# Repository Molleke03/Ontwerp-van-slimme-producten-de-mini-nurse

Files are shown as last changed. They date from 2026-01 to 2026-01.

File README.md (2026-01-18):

# CONVO 
*Convo, a tool for connection and conversation* <br>
_____
Convo is een innovatief communicatieapparaat ontworpen voor ouderen die zich eenzaam voelen of moeite hebben met moderne technologie. Veel bestaande digitale oplossingen zijn te complex, waardoor net de mensen die het meest nood hebben aan sociaal contact worden uitgesloten.

Het product richt zich op ouderen die eenvoud en duidelijkheid nodig hebben. Het apparaat bestaat uit een helder display, vier grote fysieke knoppen en ingebouwde speakers. Met één druk op de knop kunnen gebruikers eenvoudig contact maken met een familielid of een andere persoon die openstaat voor een babbeltje.

## Vormontwerp
Het ontwerp van CONVO is gebaseerd op de tijdloze designprincipes van BRAUN. De volledig witte behuizing wordt verfijnd door zachte zilveren accenten, die de draaiknop, drukknoppen en de afgeronde randen van de body subtiel benadrukken. Deze rustige en herkenbare vormgeving zorgt ervoor dat CONVO vertrouwd aanvoelt en harmonieus past binnen verschillende woonomgevingen.

github 2

### Ontwikkelproces van CONVO
Bij de creatie van het product werd gebruik gemaakt van de prusa MK4 3D-printer. Deze 3D-printe de knoppen, body, onderstel en de zijkanten. Volgende onderdelen werden allen uitgewerkt in de 3D-model software NX.

Schermafbeelding 2026-01-16 111215
<br>Welke setting, kleuren en hoe de onderdelen af te werken leggen we kort uit.

#### De knoppen
knoppen github

Alle knoppen werden geprint met:
- 0.15 mm QUALITY setting
- tree support
- 0.4 mm nozzle
- vulling van 15%

Knop 1 werd vervaardigd via 3D-printing met Polymaker Panchroma PLA Satin in de kleur groen.<br>
Knop 2 werd vervaardigd via 3D-printing met Polymaker Panchroma PLA Satin in de kleur rood. <br>
Knop 3, 4 en 5 werden vervaardigd via 3D-printing met Polymaker Panchroma PLA Satin in de kleur wit. Na het printproces werden de knoppen afgewerkt met een zilverkleurige spuitlak.

#### De body
body

Beide stukken werden geprint met:
- 0.15 mm QUALITY setting
- tree support
- 0.4 mm nozzle
- vulling van 30%
- Polymaker Panchroma PLA Satin in de kleur wit

Na het printproces werden van beide onderdelen de edges afgewerkt met een zilverkleurige spuitlak. Hierna werd het logo "CONVO" geplaatst op de behuizing met behulp van een stikker en werd ook dit afgewerkt met een zilveren spuitlak.

#### Het onderstel
onderstel

Volgend onderdeel werd geprint met:
- 0.15 mm QUALITY setting
- raster support
- 0.4 mm nozzle
- vulling van 15%
- Polymaker Panchroma PLA Satin in de kleur wit

#### De zijkanten
zijkanten

Volgend onderdeel werd geprint met:
- 0.15 mm QUALITY setting
- 0.4 mm nozzle
- vulling van 15%
- Polymaker Panchroma PLA Satin in de kleur wit

## Elektronica
### Benodigdheden
Het systeem bestaat uit:
- Raspberry Pi model 4B
- 5 inch HDMI-display (800x480 pixels)
- Audio amplifier TPA2016D2
- 2x speaker (3W, 8Ω)
- Encoder module (rotary encoder/ potentiometer))
- 4x drukknop
- USB-C → USB-A kabel met adapter
- Mini-HDMI → HDMI kabel
- Micro-USB → USB-A kabel met adapter
- 3.5 mm jack stereo → 2x RCA aux kabel (bewerkt)
- Arduino jumpdraadjes

### Aansluitingen
#### Raspberry Pi en voeding
De Raspberry Pi fungeert als het kloppend hart van het ontwerp en vormt de centrale besturingseenheid waaraan alle componenten zijn gekoppeld. De Raspberry Pi wordt gevoed via een USB-C-voeding die rechtstreeks op het elektriciteitsnet is aangesloten.

#### Display
De Raspberry Pi is via een HDMI-kabel verbonden met het 5 inch HDMI-display. Het videosignaal wordt digitaal via HDMI doorgestuurd.
Het display heeft een aparte voeding, die wordt aangesloten via een micro-USB-connector en een netadapter. Hierdoor kan het display onafhankelijk van de Raspberry Pi pinnen toch functioneren en wordt het beeld correct weergegeven.

#### Audio
Voor de geluidsuitvoer wordt gebruikgemaakt van de 3.5 mm stereo jack-uitgang van de Raspberry Pi. Deze uitgang is verbonden met een 3.5 mm jack naar 2 × RCA aux kabel.
De RCA-connectoren zijn afgeknipt zodat de afzonderlijke signaaldraden handmatig konden worden gesoldeerd.

De gesoldeerde Arduino-draadjes zijn aangesloten op de audio amplifier TPA2016D2 via de volgende aansluitingen:
- R+ en R- voor het rechter audiokanaal
- L+ en L- voor het linker audiokanaal

Om de audio amplifier correct te laten functioneren, zijn bijkomende verbindingen met de Raspberry Pi gemaakt:
- VDD en I2C van de amplifier zijn verbonden met de 5 V voeding van de Raspberry Pi (pin 2)
- GND van de amplifier is verbonden met GND van de Raspberry Pi (pin 14)

Aan de uitgangszijde van de audio amplifier zijn twee luidsprekers aangesloten. Hierbij wordt telkens de positieve pool (R+ en L+) met de positieve uitgang verbonden en de negatieve pool (R- en L-) met de negatieve uitgang.

#### Encoder module (potentiometer)
Voor het regelen van het volume wordt een encoder module gebruikt. Deze is als volgt aangesloten op de Raspberry Pi:
- GND → GND van de Raspberry Pi (pin 4)
- VCC (+) → 3.3 V van de Raspberry Pi (pin 17)
(de encoder werkt uitsluitend op 3.3 V)
- SW → GPIO25 (pin 22)
- DT → GPIO8 (pin 24)
- CLK → GPIO7 (pin 26)

Door het draaien van de encoder kan het volume aangepast worden.

#### Drukknoppen
Tot slot zijn er vier drukknoppen voorzien voor de bediening van het display en de gebruikersinterface. De knoppen zijn van links naar rechts toegewezen aan de volgende functies:
- Back
- Confirm
- Up
- Down

Elke drukknop is aangesloten volgens hetzelfde principe:
- Eén pin → GND van de Raspberry Pi (pin 6)
- Eén pin → GPIO-pin

De GPIO-toewijzing is als volgt:
- Back knop → GPIO23 (pin 16)
- Confirm knop → GPIO22 (pin 15)
- Up knop → GPIO27 (pin 13)
- Down knop → GPIO17 (pin 11)

Omdat meerdere draden op dezelfde pin van de Raspberry Pi uitkomen, worden hersluitbare lasklemmen van het merk Kopp gebruikt om de verbindingen overzichtelijk en veilig te houden.

Onderstaande afbeelding heeft het gehele schema weer om alles wat te verduidelijken.
Elektronica schema

## Code

### Uitvoeren
1. Start de Raspberry Pi en log in.
2. Plaats alle codebestanden, afbeeldingen en het geluidsfragment volgens de mapstructuur hieronder op de Raspberry Pi.
3. Pas de locatie van het geluidsfragment in `scene5.py` aan aan de hand van de locatie op de Raspberry Pi.
4. Open **Thonny Python IDE**.
5. Installeer vereiste **libraries** (zie onderstaande sectie).
6. Open het Python-bestand `main.py` via **File → Open**.
7. Sluit eventuele hardware aan op de GPIO-pinnen.
8. Klik op **Run (F5)** om het script uit te voeren.

---

### Mapstructuur

<ul class="tree">
  <li>📁 Python_finaal
    <ul>
      <li>📄 main.py </li>
        <li>📄 profiles.py </li>
      <li>📄 scene0.py </li>
        <li>📄 scene1.py </li>
        <li>📄 scene2.py </li>
        <li>📄 scene3.py </li>
        <li>📄 scene4.py </li>
        <li>📄 scene5.py </li>
      <li>📁 images
        <ul>
          <li>🖼️ megafoon.png</li>
          <li>🖼️ bel_blauw.png</li>
          <li>🖼️ bel_wit.png</li>
          <li>🖼️ + grijs.png</li>
          <li>🖼️ + groen.png</li>
          <li>🖼️ hart_grijs.png</li>
          <li>🖼️ hart_groen.png</li>
        </ul>
      </li>
      <li>📁 geluid
        <ul>
          <li>📄 gesprek.mp3</li>
        </ul>
      </li>
    </ul>
  </li>
</ul>

### Libraries
#### Standaard op Raspberry Pi OS
- tkinter
- queue
- time
- datetime
- subprocess
- RPi.GPIO
- gpiozero

#### Externe libraries
- Pillow
- pygame

Installatie (indien nodig):
```bash
pip3 install pillow pygame
sudo apt install python3-gpiozero python3-rpi.gpio
```

### Uitleg code
De uitleg van de opbouwing van de code is te vinden in elk code bestand.

### Flowchart
De logica van de code volgt onderstaande flowchart:

Flowchart

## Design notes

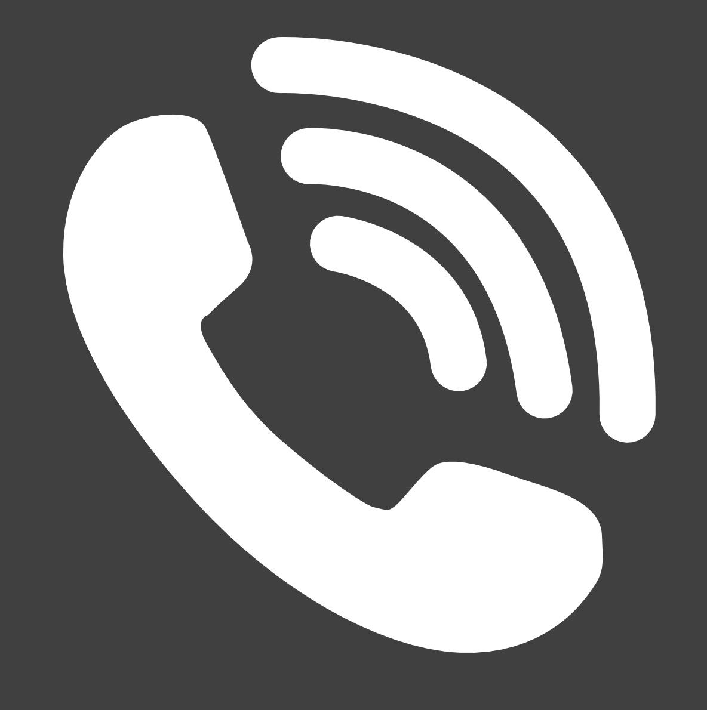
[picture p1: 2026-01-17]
codes/images/bel_wit.png

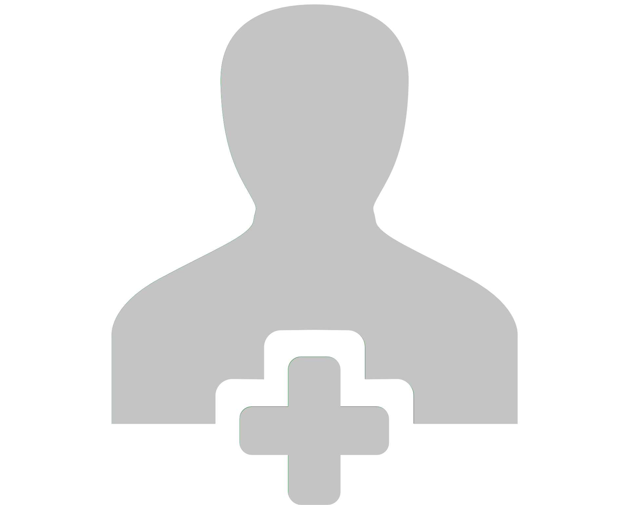
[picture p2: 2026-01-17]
codes/images/+ grijs.png

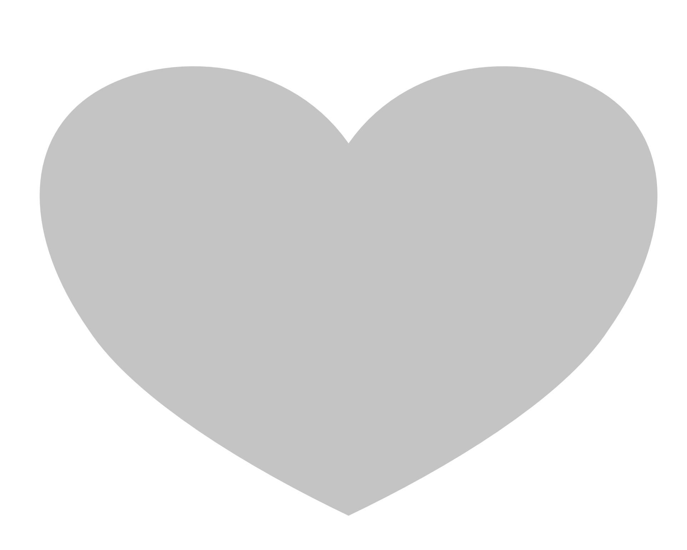
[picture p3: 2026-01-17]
codes/images/hart_grijs.png

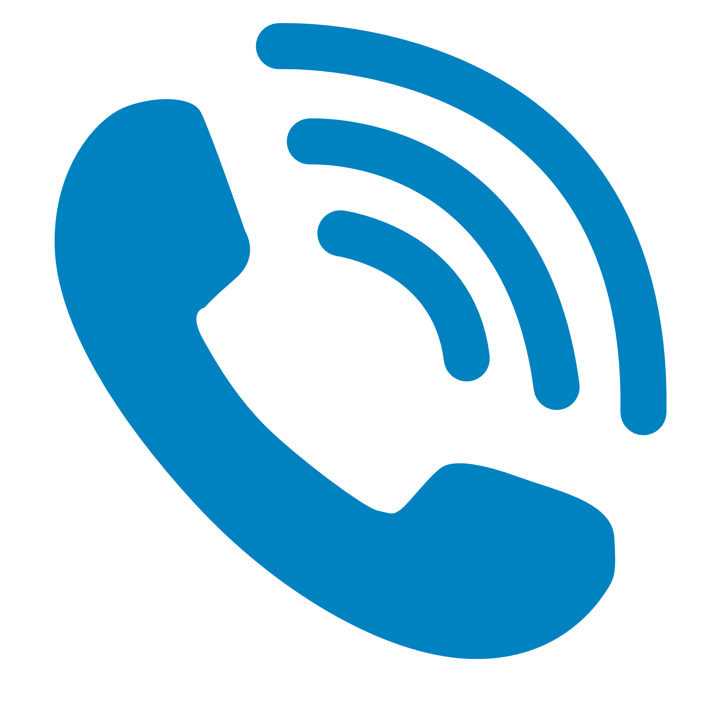
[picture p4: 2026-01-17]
codes/images/bel_blauw.png

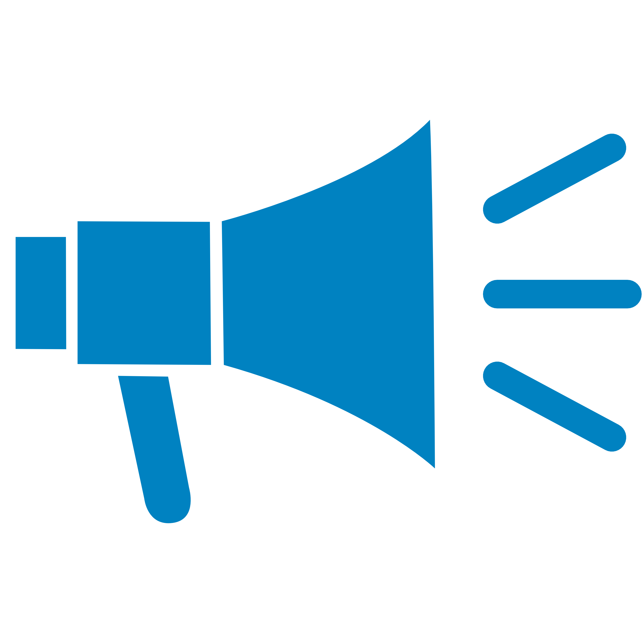
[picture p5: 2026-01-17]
codes/images/megafoon.png

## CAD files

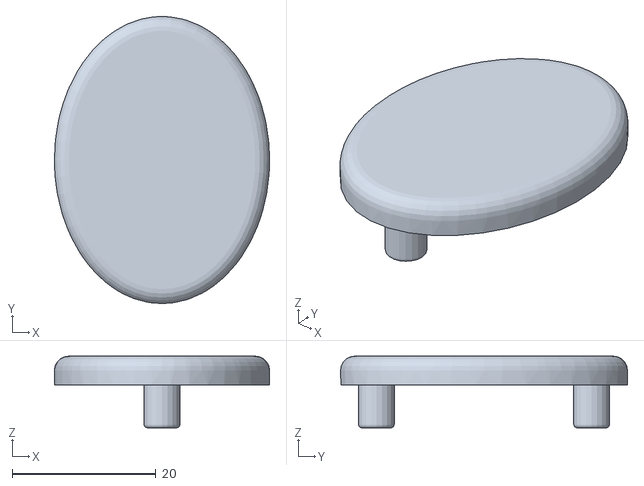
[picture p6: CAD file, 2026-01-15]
CAD bestanden/knop 1.stl
30.0 x 40.0 x 10.0

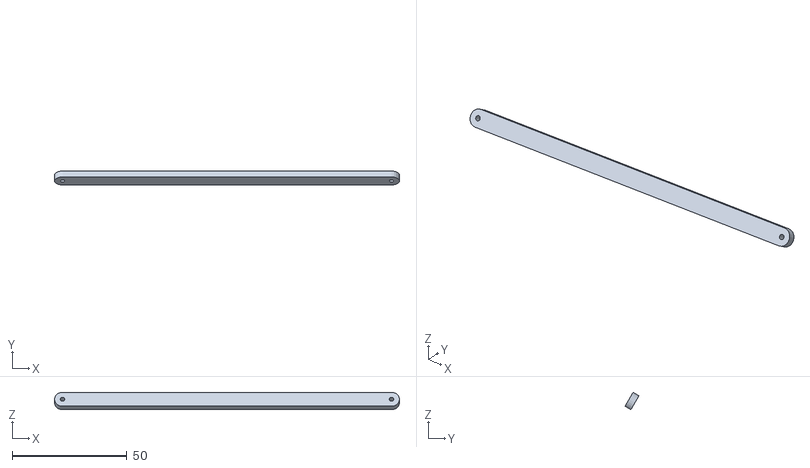
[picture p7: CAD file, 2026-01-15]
CAD bestanden/versteveging display.stl
150.5 x 6.10 x 7.56

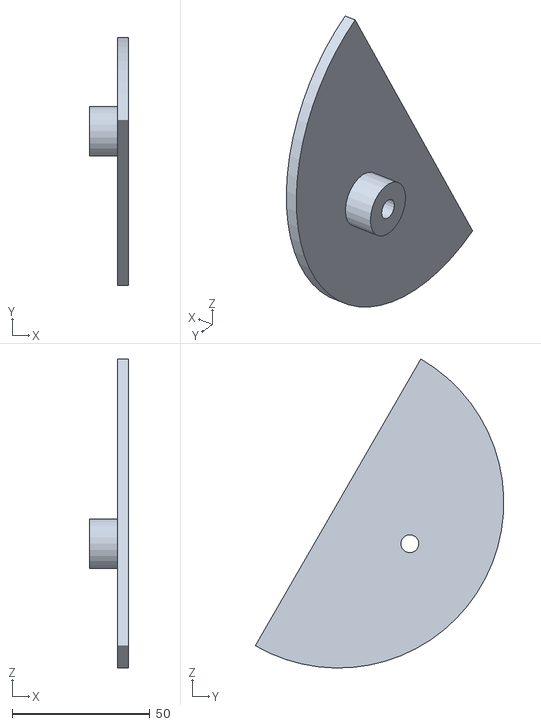
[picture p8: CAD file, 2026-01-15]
CAD bestanden/zijkant 1 body.stl
14.0 x 90.2 x 112.2

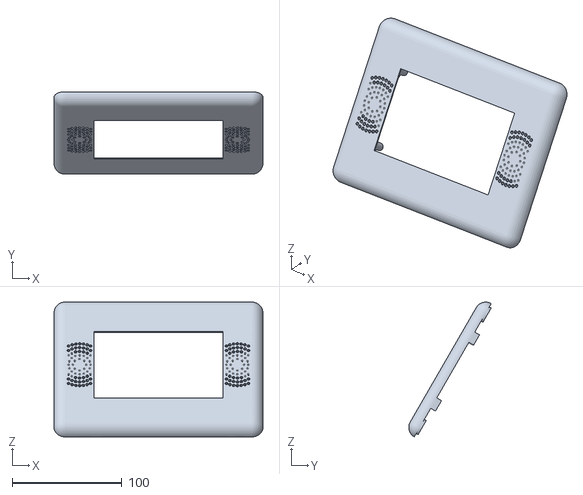
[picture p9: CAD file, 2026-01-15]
CAD bestanden/de body 1.stl
190.0 x 75.0 x 122.6

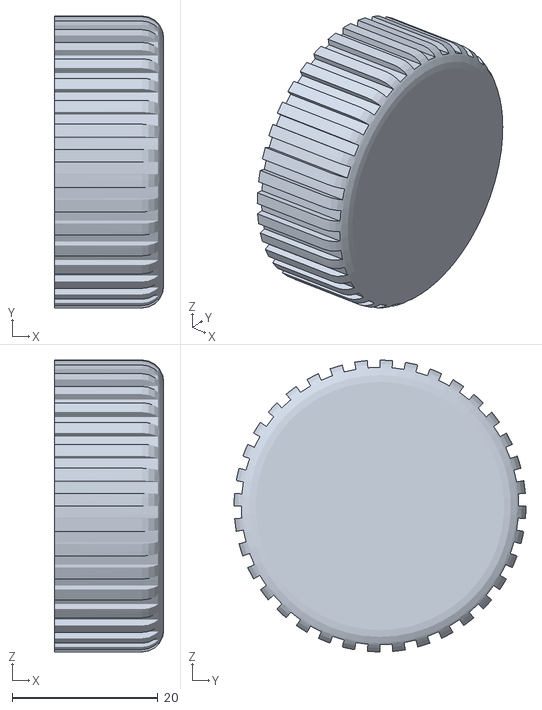
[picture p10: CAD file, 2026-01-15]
CAD bestanden/ronde knop volume.stl
15.0 x 40.0 x 40.0

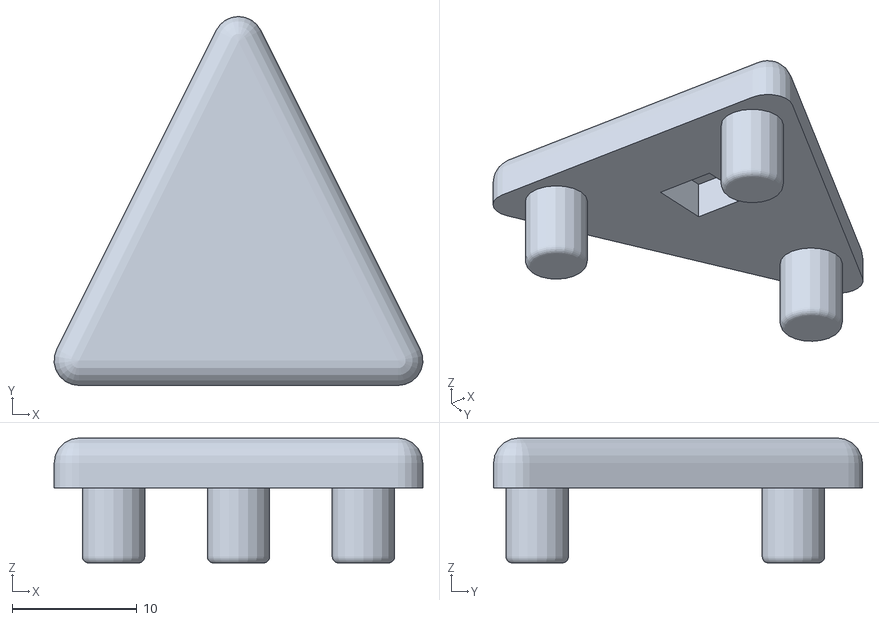
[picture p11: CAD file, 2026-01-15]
CAD bestanden/knop 2.stl
29.5 x 29.5 x 10.0

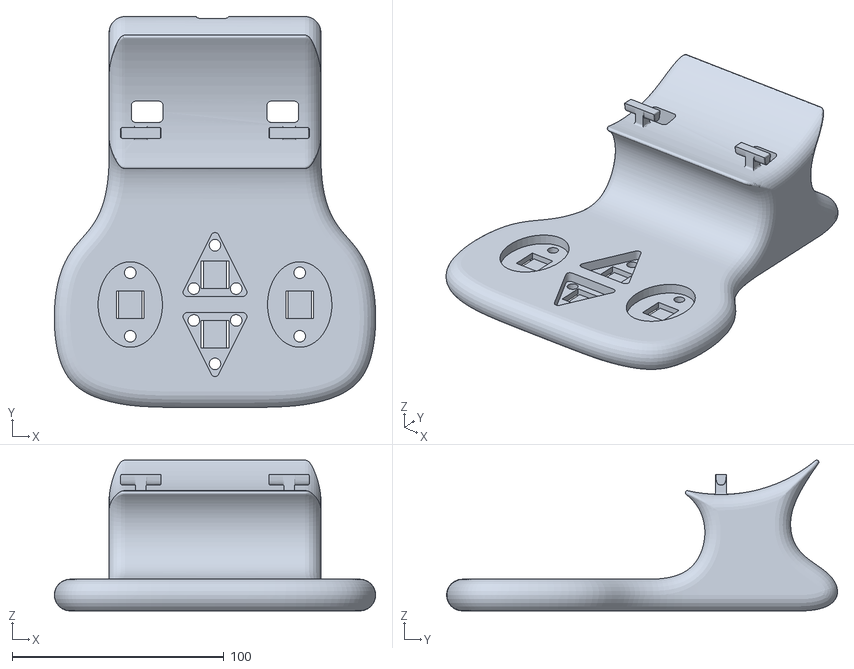
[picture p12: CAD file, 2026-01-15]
CAD bestanden/onderstel.stl
151.7 x 184.6 x 71.2

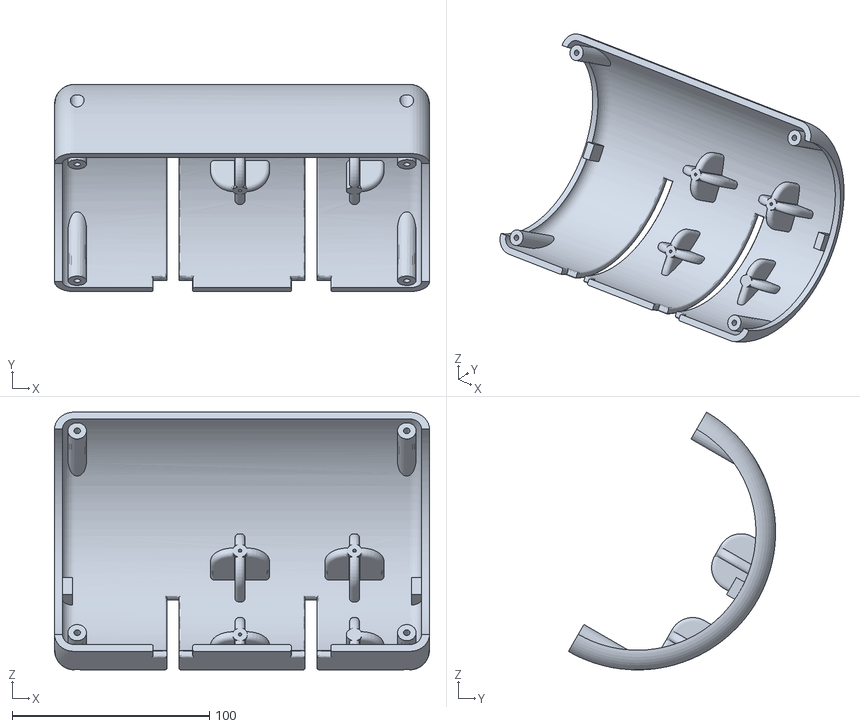
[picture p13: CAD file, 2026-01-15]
CAD bestanden/de body_2.stl
190.0 x 105.0 x 130.6

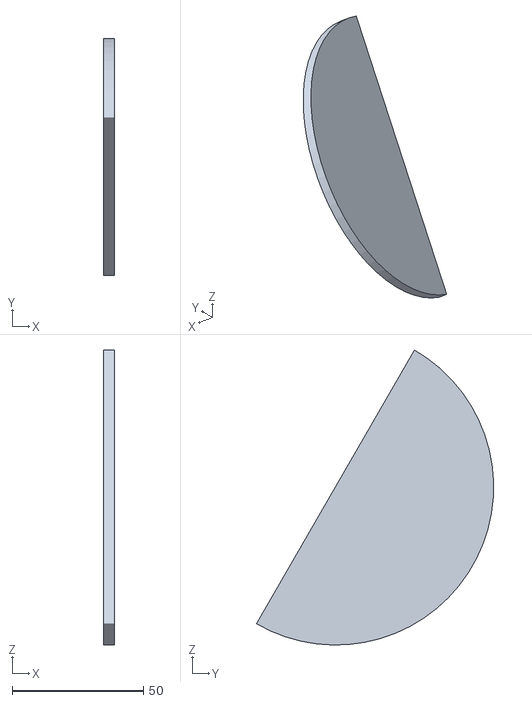
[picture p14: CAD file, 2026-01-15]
CAD bestanden/zijkant 2 body.stl
4.00 x 90.2 x 112.2

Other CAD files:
CAD bestanden/knop 4.stl
CAD bestanden/knop 3.stl

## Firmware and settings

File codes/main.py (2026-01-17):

# ============================================================
# MAIN APPLICATION
# ============================================================
# This program is a button-controlled graphical application
# designed to run on a Raspberry Pi.
#
# It shows different screens (called "scenes") on a display
# and allows the user to navigate between them using
# physical buttons connected to GPIO pins.
# ============================================================


# ================================
# IMPORTS
# ================================

import tkinter as tk
# tkinter is used to create the graphical user interface (GUI)

import queue
# queue is used to safely store button press events

import time
# time is used to track inactivity and button press timing

from gpiozero import Button
# gpiozero allows interaction with physical GPIO buttons


# ================================
# IMPORT SCENES
# ================================
# Each Scene represents a different screen in the application

from scene0 import Scene0  # Idle / start screen
from scene1 import Scene1  # Menu: Contacten active
from scene2 import Scene2  # Menu: Ontmoeten active
from scene3 import Scene3  # Profile selection
from scene4 import Scene4  # Waiting screen
from scene5 import Scene5  # Final / confirmation screen


# ================================
# GPIO PIN NUMBERS
# ================================
# These values correspond to physical GPIO pins on the Raspberry Pi

BUTTON1_PIN = 17        # Navigation button (down / next)
BUTTON2_PIN = 27        # Navigation button (up / previous)
BUTTON_CONFIRM = 22    # Confirm selection
BUTTON_BACK = 23       # Go back


# ================================
# EVENT QUEUE
# ================================
# This queue stores button press events as (pin, timestamp)
# Events are processed one by one in the main loop

event_queue = queue.Queue()


# ================================
# BUTTON SETUP
# ================================
# This function creates a GPIO button and connects it
# to the event queue when pressed

def setup_button(pin):
    button = Button(
        pin,
        pull_up=True,
        bounce_time=0.2
    )
    # pull_up=True ensures stable electrical behavior
    # bounce_time prevents multiple false triggers

    button.when_pressed = lambda: event_queue.put((pin, time.time()))
    # When pressed, store the pin number and press time in the queue

    return button


# Create button objects
button1 = setup_button(BUTTON1_PIN)
button2 = setup_button(BUTTON2_PIN)
button_confirm = setup_button(BUTTON_CONFIRM)
button_back = setup_button(BUTTON_BACK)


# ================================
# MAIN APPLICATION CLASS
# ================================
# This class represents the entire application window

class App(tk.Tk):

    # Time in seconds before returning to the start screen
    TIMEOUT_SECONDS = 60

    def __init__(self):
        super().__init__()

        # ----------------
        # WINDOW SETTINGS
        # ----------------

        self.title("Gecombineerde Scenes")
        # Set the window title

        self.configure(bg="white")
        # Set background color

        # Enable fullscreen mode
        self.fullscreen = True
        self.attributes("-fullscreen", True)
        self.attributes("-topmost", True)

        # Hide mouse cursor (touch / button only interface)
        self.config(cursor="none")

        # Keyboard shortcuts (for development/testing)
        self.bind("<F11>", self.toggle_fullscreen)
        self.bind("<Escape>", self.exit_fullscreen)

        # Configure root grid so content resizes correctly
        self.grid_rowconfigure(0, weight=1)
        self.grid_columnconfigure(0, weight=1)


        # ----------------
        # SCENE CONTAINER
        # ----------------
        # This frame holds all scenes
        # Only one scene is visible at a time

        self.container = tk.Frame(self, bg="white")
        self.container.grid(row=0, column=0, sticky="nsew")
        self.container.grid_rowconfigure(0, weight=1)
        self.container.grid_columnconfigure(0, weight=1)


        # ----------------
        # STATIC SCENES
        # ----------------
        # These scenes are created once and reused

        self.frames = {}
        for Scene in (Scene0, Scene1, Scene2):
            frame = Scene(self.container, self)
            self.frames[Scene] = frame
            frame.grid(row=0, column=0, sticky="nsew")


        # ----------------
        # DYNAMIC SCENES
        # ----------------
        # These scenes are created only when needed

        self.scene3 = None
        self.scene4 = None
        self.scene5 = None

        self.current_scene = None

        # Start application on Scene0
        self.show_frame(Scene0)

        # Track last user interaction
        self.last_activity_time = time.time()

        # Start polling the event queue
        self.poll_queue()


    # ================================
    # FULLSCREEN HANDLERS
    # ================================

    def toggle_fullscreen(self, event=None):
        # Toggle fullscreen mode on or off
        self.fullscreen = not self.fullscreen
        self.attributes("-fullscreen", self.fullscreen)

    def exit_fullscreen(self, event=None):
        # Exit fullscreen mode
        self.fullscreen = False
        self.attributes("-fullscreen", False)


    # ================================
    # SCENE SWITCHING
    # ================================

    def show_frame(self, scene):
        # Bring a scene to the front

        frame = scene if isinstance(scene, tk.Frame) else self.frames[scene]
        frame.tkraise()

        self.current_scene = frame
        self.last_activity_time = time.time()


    # ================================
    # EVENT QUEUE POLLING
    # ================================
    # This function runs repeatedly and handles button presses

    def poll_queue(self):
        try:
            while True:
                button, timestamp = event_queue.get_nowait()
                self.last_activity_time = timestamp

                # From start screen, any button opens the menu
                if isinstance(self.current_scene, Scene0):
                    self.show_frame(Scene1)
                    continue

                # Handle button based on GPIO pin
                if button == BUTTON1_PIN:
                    self.handle_button1()
                elif button == BUTTON2_PIN:
                    self.handle_button2()
                elif button == BUTTON_CONFIRM:
                    self.handle_confirm()
                elif button == BUTTON_BACK:
                    self.handle_back()

        except queue.Empty:
            # No events waiting
            pass


        # ----------------
        # INACTIVITY TIMEOUT
        # ----------------
        # Return to Scene0 after inactivity
        # except when Scene5 is active

        if (
            time.time() - self.last_activity_time > self.TIMEOUT_SECONDS
            and not isinstance(self.current_scene, (Scene0, Scene5))
        ):
            self.show_frame(Scene0)

        # Repeat polling every 50 milliseconds
        self.after(50, self.poll_queue)


    # ================================
    # BUTTON HANDLERS
    # ================================

    def handle_button1(self):
        # Navigate forward

        if isinstance(self.current_scene, Scene3):
            self.scene3.next_profile()
            # Move to next profile

        elif isinstance(self.current_scene, Scene1):
            self.show_frame(Scene2)
            # Switch menu selection


    def handle_button2(self):
        # Navigate backward

        if isinstance(self.current_scene, Scene3):
            self.scene3.prev_profile()
            # Move to previous profile

        elif isinstance(self.current_scene, Scene2):
            self.show_frame(Scene1)
            # Switch menu selection back


    def handle_confirm(self):
        # Confirm current selection

        if isinstance(self.current_scene, Scene1):
            self.show_scene3("contacten")

        elif isinstance(self.current_scene, Scene2):
            self.show_scene3("ontmoeten")

        elif isinstance(self.current_scene, Scene3):
            self.show_scene4(self.scene3.get_current_profile_name())


    def handle_back(self):
        # Go back to previous menu

        if isinstance(self.current_scene, Scene5):
            self.scene5.stop_audio()
            self.show_frame(Scene1)

        elif isinstance(self.current_scene, Scene3):
            self.show_frame(Scene1)


    # ================================
    # DYNAMIC SCENE CREATION
    # ================================

    def show_scene3(self, pathway):
        # Create and show Scene3

        self.scene3 = Scene3(self.container, self, pathway)
        self.scene3.grid(row=0, column=0, sticky="nsew")
        self.show_frame(self.scene3)


    def show_scene4(self, name):
        # Create or update Scene4

        if not self.scene4:
            self.scene4 = Scene4(self.container, self, name)
            self.scene4.grid(row=0, column=0, sticky="nsew")
        else:
            self.scene4.update_profile_name(name)

        self.show_frame(self.scene4)

        # Automatically continue to Scene5 after 10 seconds
        self.after(10000, lambda: self.show_scene5(name))


    def show_scene5(self, name):
        # Create or update Scene5

        if not self.scene5:
            self.scene5 = Scene5(self.container, self, name)
            self.scene5.grid(row=0, column=0, sticky="nsew")
        else:
            self.scene5.update_profile_name(name)
            self.scene5.start_audio()

        self.show_frame(self.scene5)


# ================================
# APPLICATION ENTRY POINT
# ================================

if __name__ == "__main__":
    App().mainloop()

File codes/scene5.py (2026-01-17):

import tkinter as tk
# Importeer tkinter om vensters, frames en labels te maken

from PIL import Image, ImageTk
# Importeer Pillow om afbeeldingen te laden en in tkinter te tonen

import RPi.GPIO as GPIO
# Raspberry Pi GPIO-bibliotheek om fysieke pinnen te gebruiken

import time
# Om vertragingen en debouncing voor de encoder te regelen

import subprocess
# Om systeemvolume via terminalcommando's aan te passen

import pygame
# Voor audio-afspelen (loopend tijdens het bellen)


# ======================
# AUDIO-INSTELLINGEN
# ======================

AUDIO_PATH = "source path audio /geluid/gesprek.mp3"
# Pad naar het audiobestand dat wordt afgespeeld tijdens het bellen

MAX_VOLUME = 90
# Maximale toegestane volume-instelling (in procenten)

STEP = 5
# Hoeveel het volume omhoog of omlaag gaat per stap van de rotary encoder


# ======================
# GPIO PIN-INSTELLINGEN VOOR ROTARY ENCODER
# ======================

CLK = 7
# Clock-pin van de rotary encoder

DT = 8
# Data-pin van de rotary encoder

SW = 25
# Schakelaar-knop (drukknop) van de rotary encoder


class Scene5(tk.Frame):
# ======================
# Scene5: Bellen-scherm
# ======================

    def __init__(self, parent, controller=None, profile_name=None):
        # Automatisch uitgevoerd bij het aanmaken van Scene5

        super().__init__(parent, bg='white')
        # Frame initialiseren met witte achtergrond

        self.controller = controller
        # Referentie naar het hoofdprogramma opslaan

        self.profile_name = profile_name or "Peter Wilson"
        # Stel profielnaam in of gebruik standaardnaam


        # ======================
        # UI OPBOUWEN
        # ======================

        self.build_ui()
        # Creëer alle visuele elementen van de scene


        # ======================
        # ROTARY ENCODER CONFIGURATIE
        # ======================

        GPIO.setmode(GPIO.BCM)
        # Gebruik BCM-pin nummering

        GPIO.setup(CLK, GPIO.IN, pull_up_down=GPIO.PUD_UP)
        GPIO.setup(DT, GPIO.IN, pull_up_down=GPIO.PUD_UP)
        GPIO.setup(SW, GPIO.IN, pull_up_down=GPIO.PUD_UP)
        # Stel pins in als input met pull-up weerstand

        self.clk_last = GPIO.input(CLK)
        # Bewaar de huidige staat van CLK voor vergelijking bij rotatie

        self.after(10, self.poll_encoder)
        # Start het continue controleren van de encoder


        # ======================
        # AUDIO STARTEN
        # ======================

        self.start_audio()
        # Speel het belgeluid direct af


    # ======================
    # USER INTERFACE (UI)
    # ======================

    def build_ui(self):
        # Bouw het scherm met labels, afbeeldingen en knoppen

        main_frame = tk.Frame(self, bg="white")
        main_frame.pack(fill=tk.BOTH, expand=True)
        # Hoofdframe dat de volledige ruimte vult

        # ---- Titel ----
        tk.Label(main_frame,
                 text="U bent aan het bellen!",
                 font=("Arial",44,"bold"),
                 fg="black",
                 bg="white").pack(pady=(120,0))
        # Titel bovenaan het scherm

        # ---- Profielnaam ----
        self.name_label = tk.Label(main_frame,
                                   text=self.profile_name,
                                   font=("Arial",32),
                                   fg="black",
                                   bg="white")
        self.name_label.pack(pady=(0,20))
        # Toont dynamisch de naam van de persoon die gebeld wordt

        # ---- Telefoon afbeelding ----
        try:
            call_image = Image.open("images/bel_blauw.png").resize((120,120))
            self.call_photo = ImageTk.PhotoImage(call_image)
            call_lbl = tk.Label(main_frame, image=self.call_photo, bg="white")
        except Exception:
            # Als de afbeelding niet kan worden geladen
            call_lbl = tk.Label(main_frame,
                                text="[telefoon-icoon]",
                                font=("Arial",18),
                                fg="#1E73B9",
                                bg="white")
        call_lbl.pack(pady=0)
        # Toon het icoon of een tekstplaceholder

        # ---- Blauwe onderbalk ----
        bottom_height = 55
        self.bottom_bar = tk.Frame(self, bg="#0082C1", height=bottom_height)
        self.bottom_bar.pack(side=tk.BOTTOM, fill=tk.X)
        # Onderbalk onderaan het scherm


        # ---- Knoppen onderaan ----
        button_height = 90
        y_buttons = 480 - bottom_height - button_height + 20
        x_left = 0
        x_right = 800 - 320

        # Groene knop: +Contact
        self.green = tk.Canvas(self, width=320, height=button_height, bg="white", highlightthickness=0)
        self.draw_round_top_right(self.green, 0, 0, 320, button_height, 20, fill="#327FBE", outline="#327FBE")
        self.draw_round(self.green, 8,8,312,82,20, fill="#2E7D32", outline="#327FBE", width=4)
        self.green.create_text(160,45, text="+Contact", font=("Arial",36,"bold"), fill="white")
        self.green.place(x=x_left, y=y_buttons)

        # Rode knop: Menu
        self.red = tk.Canvas(self, width=320, height=button_height, bg="white", highlightthickness=0)
        self.draw_round_top_left(self.red, 0,0,320,button_height,20, fill="#327FBE", outline="#327FBE")
        self.draw_round(self.red, 8,8,312,82,20, fill="#E53935", outline="#327FBE", width=4)
        self.red.create_text(160,45, text="Menu", font=("Arial",36,"bold"), fill="white")
        self.red.place(x=x_right, y=y_buttons)
        # Plaats beide knoppen aan de onderkant


    # ======================
    # AUDIO FUNCTIES
    # ======================

    def start_audio(self):
        # Start het belgeluid in een lus
        pygame.mixer.init()
        pygame.mixer.music.load(AUDIO_PATH)
        pygame.mixer.music.set_volume(1.0)
        pygame.mixer.music.play(-1)

    def stop_audio(self):
        # Stop het belgeluid en maak resources vrij
        pygame.mixer.music.stop()
        pygame.mixer.quit()
        GPIO.cleanup()


    # ======================
    # ROTARY ENCODER FUNCTIES
    # ======================

    def poll_encoder(self):
        # Blijf continu de encoder controleren
        clk = GPIO.input(CLK)
        dt = GPIO.input(DT)

        if clk != self.clk_last and clk == GPIO.LOW:
            # Detecteer draaiing
            if dt != clk:
                self.volume_up()
            else:
                self.volume_down()
            time.sleep(0.03)  # debounce

        self.clk_last = clk

        # Drukknop SW
        if GPIO.input(SW) == GPIO.LOW:
            self.toggle_mute()
            time.sleep(0.3)  # debounce

        self.after(10, self.poll_encoder)
        # Herhaal polling


    # ======================
    # VOLUME CONTROLE
    # ======================
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

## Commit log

2026-01-14 Revise Raspberry Pi project requirements and connections
    Updated the requirements and connections for the Raspberry Pi project, including details for components and wiring.
2026-01-14 Fix formatting of cable descriptions in README.md
2026-01-18 Document GPIO pin assignments for buttons
    Added GPIO pin assignments for buttons.
2026-01-18 Update README with encoder and button details
    Added information about the rotary encoder and button functions.
2026-01-18 Update GPIO button labels in README
